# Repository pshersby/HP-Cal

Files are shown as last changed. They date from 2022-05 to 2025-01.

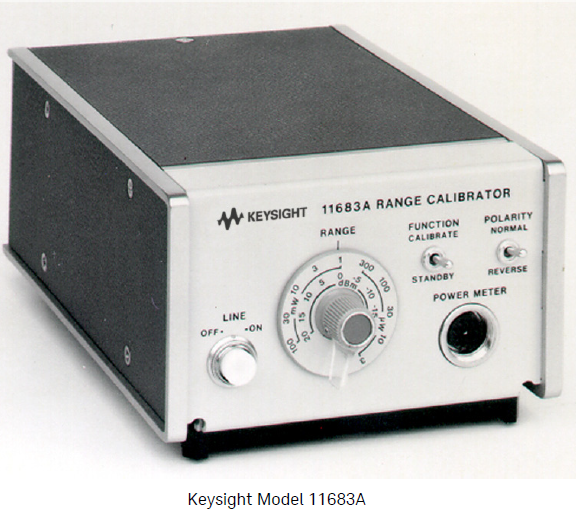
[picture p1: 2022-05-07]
Art/original.PNG

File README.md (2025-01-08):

# HP-Cal
 HP RF Meter Calibration

Version 1.1.1 8th Jan 2025
A3A1R1 previously labelled as both 196 and 464K in BOM corrected to 464k
Missing track from C11 put back in to join C11 to regulator
Missing track to base of Q11 replaced

Version 1.1. 
Contains th emodifications and fixes descbibed in my toutube videos.  Note that currently at rel 1.1 the artwork for the front panel and the 3d brackets have not been updated for the modified PCB layout which includes wider switch spacing etc. 

These Are Altium CircuitStudio schematics and PCB, they might load in Altium maker.

DefaultConfiguration/outputs contains the gerber and drill files, and a JLCPCB file with all the files needed for JLCPCB to make the pcb
The BOM is also in the above folder

A PDF with schematics, assembly locations etc is also available in that folder

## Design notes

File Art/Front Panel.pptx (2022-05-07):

## Front Panel

10-way 10mm
Sw 6.1mm
BNC 13mm
Out 18mm
Power 19mm

PKS 11683A
Range Calibrator

Calibrate

Standby

Int Ref

External

Positive

Reverse

Ref Out

Ref In

## Front Panel

10-way 10mm
Sw 6.1mm
BNC 13mm
Out 18mm
Power 19mm

PKS 11683A
Range Calibrator

Zero/
Standby

Calibrate

Int Ref

External

Positive

Reverse

Power

Ref Out

Ref In

Output

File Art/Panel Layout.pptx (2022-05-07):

## Panel Layout

60

30

30

30

PKS 11683A
Range Calibrator

Function
Calibrate

Standby

Reference
Internal

External

Output
Normal

Reverse

Ref Out

Ext Ref In

Power Meter

47

35

26

23

30

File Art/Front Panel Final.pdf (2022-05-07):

# Front Panel

10-way 10mm
Sw 6.1mm
BNC 13mm
Out 18mm
Power 19mm

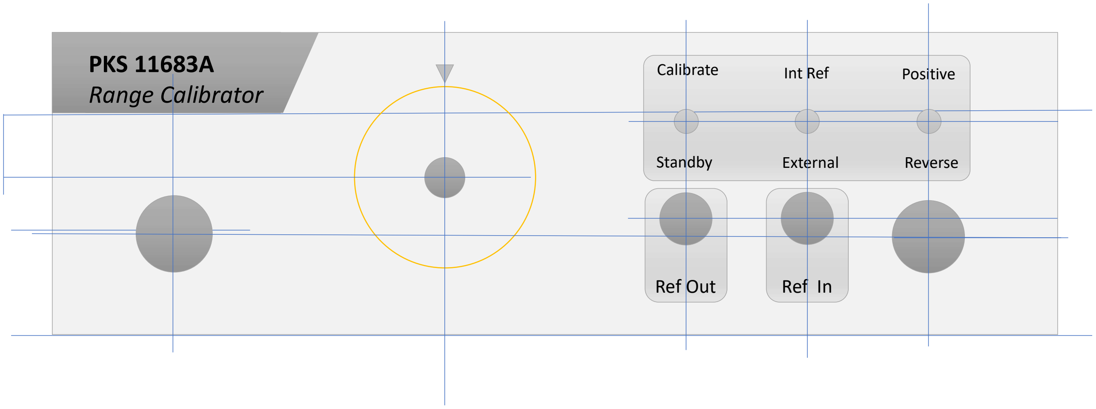
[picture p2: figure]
Ref Out; Ref; Calibrate; Standby; Int Ref; Positive; External; Reverse; PKS 11683A Range Calibrator

# Front Panel

10-way 10mm
Sw 6.1mm
BNC 13mm
Out 18mm
Power 19mm

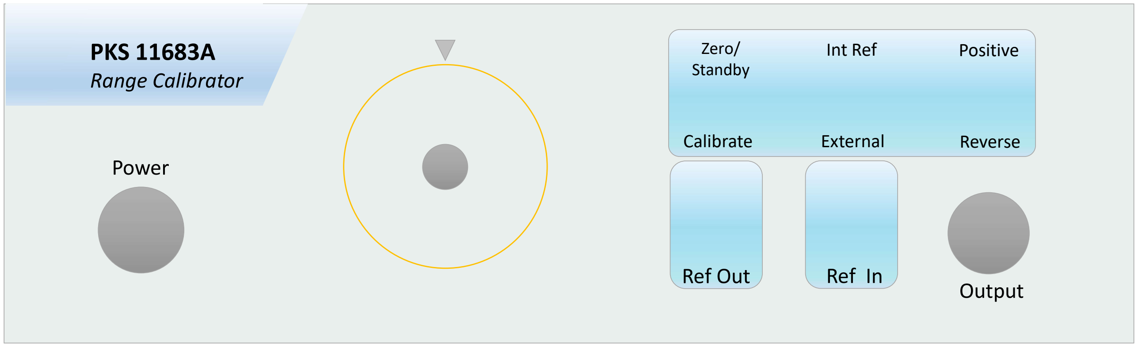
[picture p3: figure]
Ref Out; Ref In; Zero/ Standby; Calibrate; Int Ref; Positive; External; Reverse; PKS 11683A Range Calibrator; Power; Output

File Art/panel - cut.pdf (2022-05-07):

# Front Panel

10-way 10mm
Sw 6.1mm
BNC 13mm
Out 18mm
Power 19mm

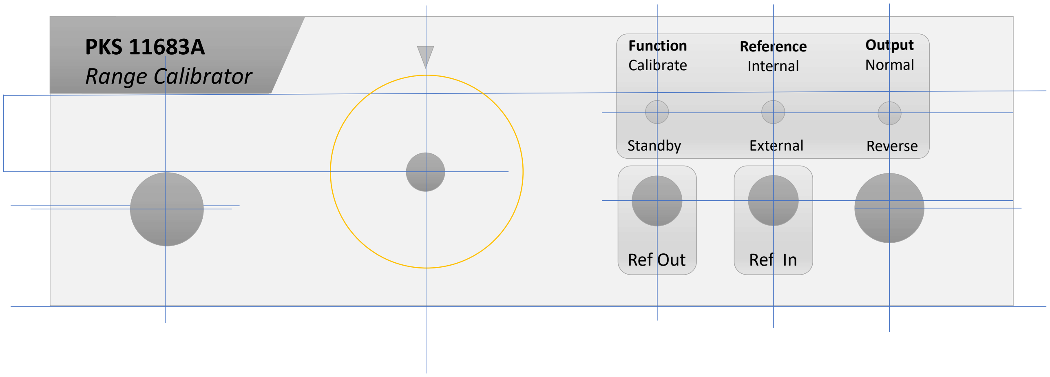
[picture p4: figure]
Ref Out; Ref; Function Calibrate; Standby; Reference Internal; Output Normal; External; Reverse; PKS 11683A Range Calibrator

# Front Panel

10-way 10mm
Sw 6.1mm
BNC 13mm
Out 18mm
Power 19mm

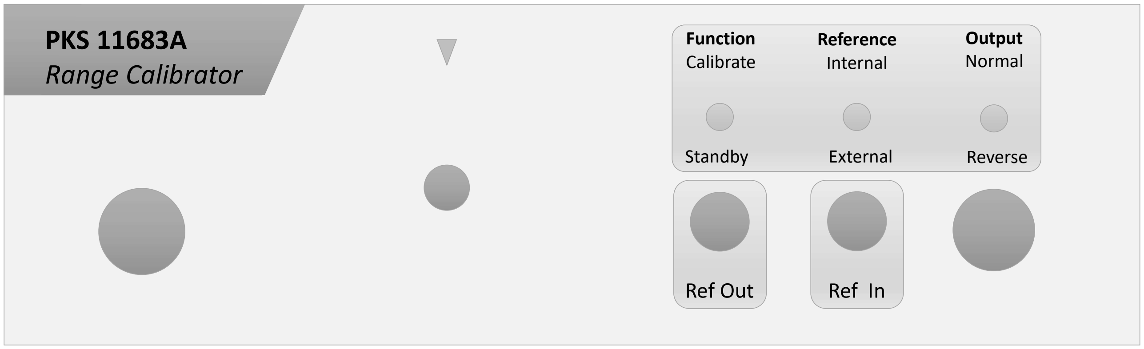
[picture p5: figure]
Ref Out; Ref In; Function Calibrate; Standby; Reference Internal; Output Normal; External; Reverse; PKS 11683A Range Calibrator

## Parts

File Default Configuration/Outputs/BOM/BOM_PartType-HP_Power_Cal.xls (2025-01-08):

Item # | Quantity | Designator | Description | Footprint | Comment | LibRef
1 | 1 | A1R3 | Resistor 196K 1% 0805 1/8W 10ppm/C | RESC2013X70X40LL20T20 | RES 196K 1% 0805 | CMP-2001-00110-5
2 | 1 | A3A1R1 | Resistor 464K 1% 0805 0.2W 10ppm/C | RESC2013X70X40LL20T20 | 464K 1% 0805 | CMP-2001-00110-5
3 | 1 | A3R2 | Resistor 3K!6 1% 0805 1/8W 10ppm/C | RESC2013X70X40LL20T20 | RES 3K16 1% 0805 | CMP-2001-00110-5
4 | 1 | A3R3 | Resistor 316 1% 0805 1/8W 10ppm/C | RESC2013X70X40LL20T20 | RES 316 1% 0805 | CMP-2001-00110-5
5 | 1 | BNC1 | BNC PCB Mount | BNC PCB Plastic | Ref Out | BNC PCB
6 | 1 | BNC2 | BNC Ref Out | BNC PCB Plastic | Ref In | BNC PCB
7 | 2 | C1, C9 | 47uF Tant 4V 1411 | FP-TAJB-MFG | 47uF TA | CMP-04424-000035-1
8 | 4 | C2, C3, C7, C8 | 100pF 0805 | CAPC2113X88X50NL30T25 | 100pF 0805 | CMP-2007-00001-1
9 | 3 | C4, C12, C14 | 1206 (3216 Metric) Chip Capacitor | CAPC1206(3216)150_L | 3.3UF | CMP-1590-00001-1
10 | 1 | C5 | 0.1uF 0805 | CAPC2113X88X50NL30T25 | 0.1uF 0805 | CMP-2007-00001-1
11 | 1 | C6 | 0.01uF 0805 | CAPC2113X88X50NL30T25 | 0.01uF 0805 | CMP-2007-00001-1
12 | 1 | C10 | CAP TANT 100u 10V | FP-TPE-D4-MFG | 100u 10V TA | CMP-05428-000010-1
13 | 1 | C11 | CAP TANT 10u 25V | FP-TPE-D4-MFG | 10u 25V TA | CMP-05428-000010-1
14 | 1 | C13 | 1uF 0805 | CAPC2113X88X50NL30T25 | 1uF 0805 | CMP-2007-00001-1
15 | 1 | CHS-GND | Socket | PIN1 | T0 Chassis Gnd | Socket
16 | 1 | Fuse | Fuse | Fuse Holder 20mm PCB with Cover | Fuse 50mA T | Fuse
17 | 2 | IBC1, IBC2 | Header, 4-Pin | HDR1X4 | Header 4 | Header 4
18 | 1 | L1 | Inductor 6.8uH | 2.5x2 Inductor | 6.8uH | Inductor
19 | 4 | L, N, SW-1, SW-2 | Socket | PIN1 | Socket | Socket
20 | 1 | P6 | Header, 2-Pin | HDR1X2 | Power In | Header 2
21 | 1 | P7 | Header, 2-Pin | HDR1X2 | Power Ref | Header 2
22 | 1 | P8 | Header, 2-Pin | HDR1X2 | Power LED | Header 2
23 | 1 | P9 | Header, 8-Pin | HDR1X8 | Header 8 | Header 8
24 | 1 | P10 | Header, 2-Pin | HDR1X2 | Ext 18-24V | Header 2
25 | 2 | Q1, Q2 | JFET - VHF / UJFET Chopper | ONSC-SOT-23-3-318-08_V | MMBFJ111 | CMP-1062-00038-1
26 | 1 | Q3 | 2SC3837K | SC-59 | 2SC3837K | NPN
27 | 1 | R1 | Resistor 31.6 0.1% 0805 0.2W 10ppm/C | RESC2013X70X40LL20T20 | RES 31.6 0.1% 0805 | CMP-2001-00110-5
28 | 1 | R2 | Resistor 0.02 1% 0805 0.5W 50ppm/C | RESC2013X70X40LL20T20 | RES 0.02 1% 0805 | CMP-2001-00110-5
29 | 1 | R3 | Resistor 68.1 0.1% 0805 0.2W 10ppm/C | RESC2013X70X40LL20T20 | RES 68.1 0.1% 0805 | CMP-2001-00110-5
30 | 1 | R4 | Resistor 0.27 1% 0805 0.2W 10ppm/C | RESC2013X70X40LL20T20 | RES 0.27 1% 0805 | CMP-2001-00110-5
31 | 2 | R5, R5a | Resistor 432 0.1% 0805 0.2W 10ppm/C | RESC2013X70X40LL20T20 | RES 432 0.1% 0805 | CMP-2001-00110-5
32 | 1 | R6 | Resistor 0.39 1% 0805 0.2W 10ppm/C | RESC2013X70X40LL20T20 | RES 0.39 1% 0805 | CMP-2001-00110-5
33 | 1 | R7 | Resistor 22.6 0.1% 0805 0.2W 10ppm/C | RESC2013X70X40LL20T20 | RES 22.6 0.1% 0805 | CMP-2001-00110-5
34 | 1 | R8 | Resistor 665 0.1% 0805 0.2W 10ppm/C | RESC2013X70X40LL20T20 | RES 665 0.1% 0805 | CMP-2001-00110-5
35 | 1 | R9 | Resistor 2K2 0.5% 0805 0.2W 10ppm/C | RESC2013X70X40LL20T20 | RES 2K2 0.5% 0805 | CMP-2001-00110-5
36 | 1 | R10 | Resistor 7.32 0.1% 0805 0.2W 10ppm/C | RESC2013X70X40LL20T20 | RES 7.32 0.1% 0805 | CMP-2001-00110-5
37 | 1 | R11 | Resistor 7.15K 0.1% 0805 0.2W 10ppm/C | RESC2013X70X40LL20T20 | RES 7.15K 0.1% 0805 | CMP-2001-00110-5
38 | 1 | R12 | Resistor 59 0.1% 0805 0.2W 10ppm/C | RESC2013X70X40LL20T20 | RES 59 0.1% 0805 | CMP-2001-00110-5
39 | 1 | R13 | Resistor 100 0.1% 0805 0.2W 10ppm/C | RESC2013X70X40LL20T20 | RES 100 0.1% 0805 | CMP-2001-00110-5
40 | 2 | R14, R14b | Resistor 53.6K 0.1% 0805 0.2W 10ppm/C | RESC2013X70X40LL20T20 | RES 53.6K 0.1% 0805 | CMP-2001-00110-5
41 | 2 | R15, R15a | Resistor 160 0.1% 0805 0.2W 10ppm/C | RESC2013X70X40LL20T20 | RES 160 0.1% 0805 | CMP-2001-00110-5
42 | 2 | R16, R16a | Resistor 274K 0.1% 0805 0.2W 10ppm/C | RESC2013X70X40LL20T20 | RES 274K 0.1% 0805 | CMP-2001-00110-5
43 | 1 | R17 | Resistor 2.8K 0.1% 0805 0.2W 10ppm/C | RESC2013X70X40LL20T20 | RES 2.8K 0.1% 0805 | CMP-2001-00110-5
44 | 1 | R18 | Resistor 536K 0.1% 0805 1/8W 10ppm/C | RESC2013X70X40LL20T20 | RES 536K 0.1% 0805 | CMP-2001-00110-5
45 | 2 | R19, R19a | Resistor 25K 0.1% 0805 0.1W 10ppm/C | RESC2013X70X40LL20T20 | RES 25K 0.1% 0805 | CMP-2001-00110-5
46 | 1 | R20 | Resistor 360K 0.1% 0805 1/8W 10ppm/C | RESC2013X70X40LL20T20 | RES 360K 0.1% 0805 | CMP-2001-00110-5
47 | 1 | R21 | Resistor 3K3 0.1% 0805 0.2W 10ppm/C | RESC2013X70X40LL20T20 | RES 3K3 0.1% 0805 | CMP-2001-00110-5
48 | 1 | R29 | Resistor 196 1% 0805 0.2W 10ppm/C | RESC2013X70X40LL20T20 | RE196 1% 0805 | CMP-2001-00110-5
49 | 2 | R31, R33 | Resistor 15 1% 0805 0.2W 10ppm/C | RESC2013X70X40LL20T20 | RES 15 1% 0805 | CMP-2001-00110-5
50 | 3 | R32, R34, R35 | Resistor 1K 1% 0805 0.2W 10ppm/C, Resistor 1K1% 0805 0.2W 10ppm/C, Resistor 1K1% 0805 0.2W 10ppm/C | RESC2013X70X40LL20T20 | RES 1K 1% 0805 | CMP-2001-00110-5
51 | 1 | R36 | Resistor 240 1% 0805 0.2W 10ppm/C | RESC2013X70X40LL20T20 | RES 240 1% 0805 | CMP-2001-00110-5
52 | 1 | R37 | Resistor 2k2 5% 0805 0.2W 10ppm/C | RESC2013X70X40LL20T20 | RES 2k2 5% 0805 | CMP-2001-00110-5
53 | 1 | R38 | Resistor 10K 5% 0805 0.2W 50ppm/C | RESC2013X70X40LL20T20 | RES 10K 5% 0805 | CMP-2001-00110-5
54 | 1 | RT1 | RES 31.6 250ppm 0805 | RESC2013X70X40LL20T20 | RES 31.6 250ppm 0805 | CMP-2001-00110-5
55 | 2 | SC1, SC2 |  | ScreenConnection | ScreenConnection | ScreenConnection
56 | 1 | SW1 | Rotary Switch 10way PCB CKN10954-ND | SW_ROT_4x12 | Rotary Switch 10way | Rotary_Switch_1x10
57 | 1 | SW2 | DPDT Switch | DPDT Toggle E switch | DPDT Switch POL | DPDT Switch
58 | 1 | SW3 | CAL/SDBY DPDT | DPDT Toggle E switch | CAL/SBY DPDT | DPDT Switch
59 | 1 | SW4 | DPDT Switch | DPDT Toggle E switch | INT/EXT DPDT | DPDT Switch
60 | 1 | T1 | AC-DC Regulated Module 24V | IRM-02 Moule SM | AC-DC Reg | AC-DC Reg Module
61 | 1 | Trm1 | Trimmer | 3214W Trimmer | Trm 1k | Trimmer
62 | 1 | U1 | 500mA, Medium Current 1.2 to 37 V Adjustable Voltage Regulator, 3-Pin DPAK, Tape and Reel | TO-252_L | LM317MDT-TR | CMP-0244-00074-1

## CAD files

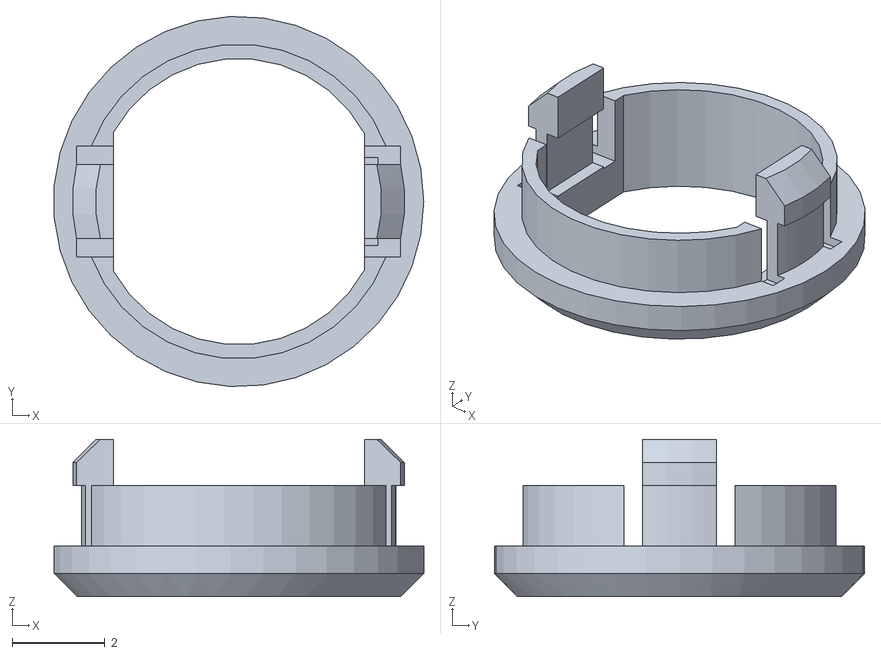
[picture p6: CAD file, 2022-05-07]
3d/bezel.stl
7.98 x 7.99 x 3.40

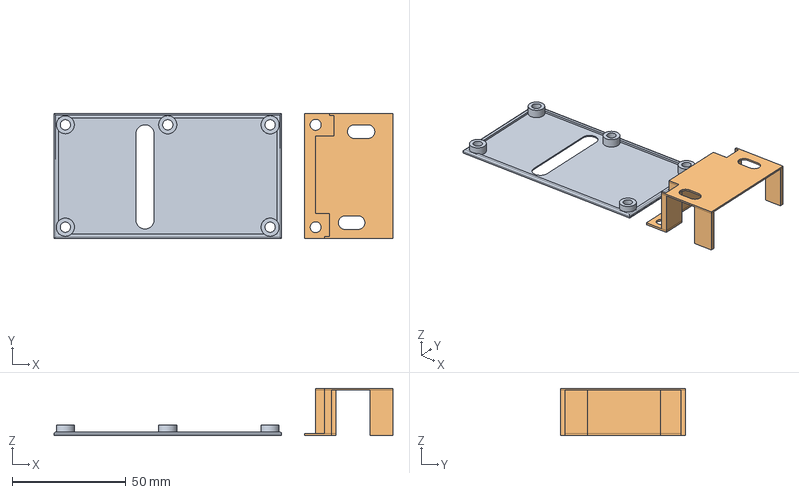
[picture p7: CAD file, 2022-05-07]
3d/HV Insulation.FCStd
149.0 x 55.0 x 20.8 mm
Insulator

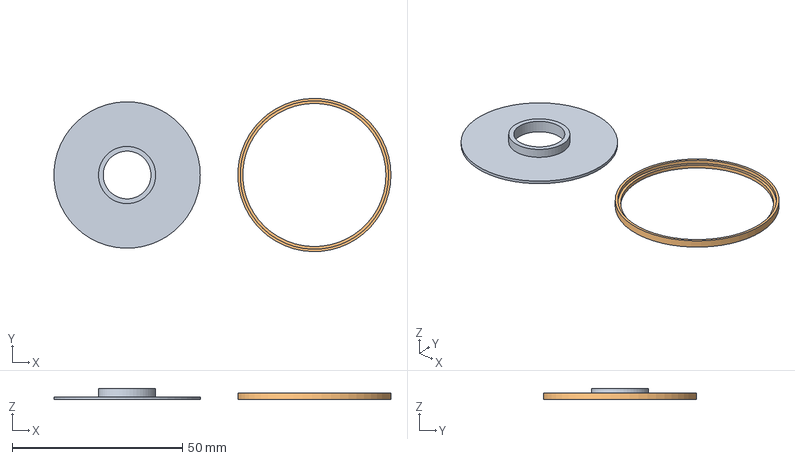
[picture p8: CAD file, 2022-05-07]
3d/knob scale ver 2 pt 1.FCStd
99.0 x 45.0 x 3.30 mm

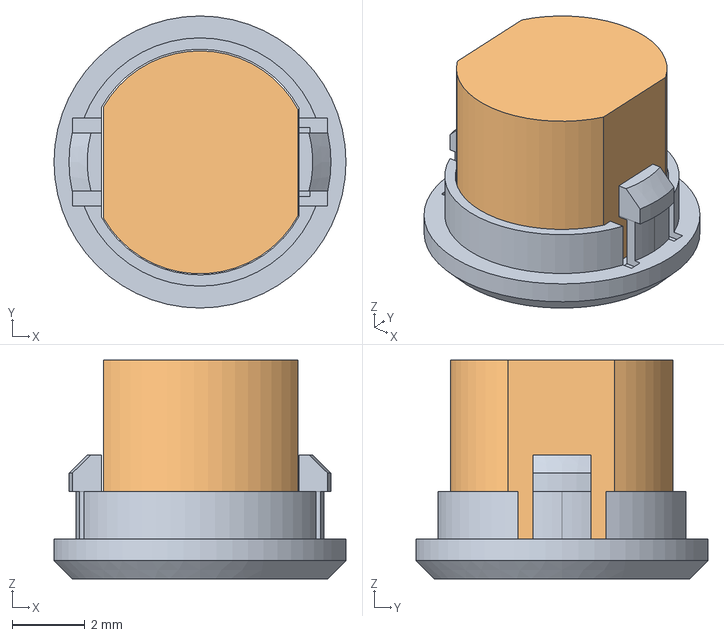
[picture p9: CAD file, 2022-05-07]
3d/switch bezel.FCStd
8.00 x 8.00 x 6.00 mm

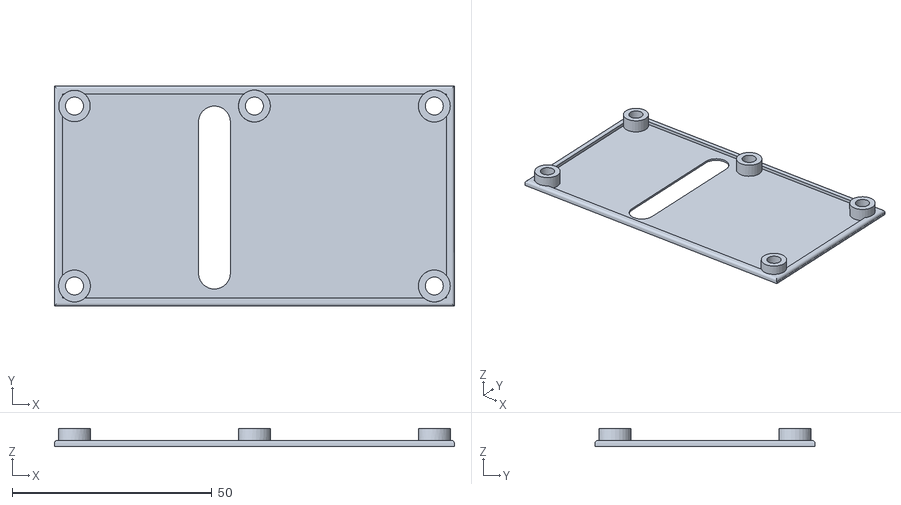
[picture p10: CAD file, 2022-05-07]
3d/Insulating Base.stl
100.0 x 55.0 x 4.60

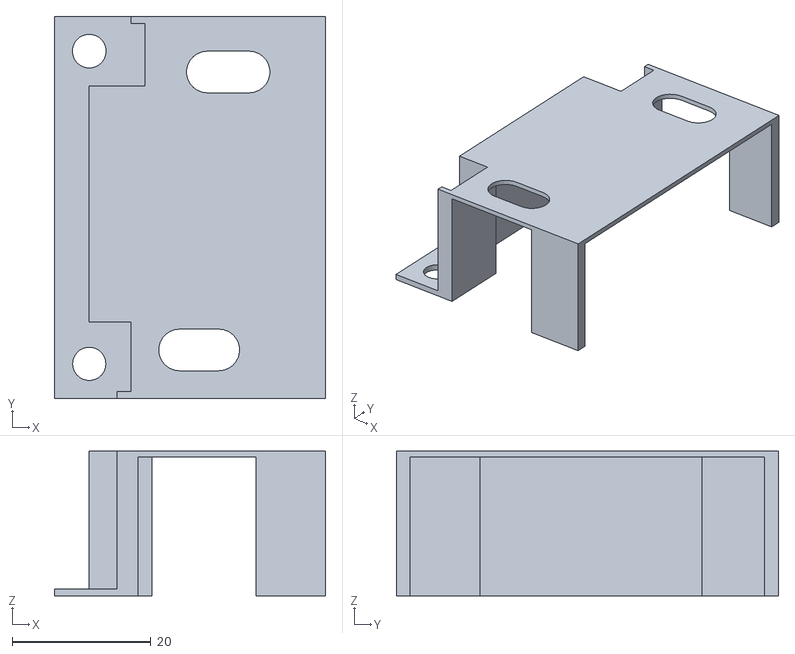
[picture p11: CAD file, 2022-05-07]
3d/Insulting Cap.stl
39.0 x 55.0 x 20.8

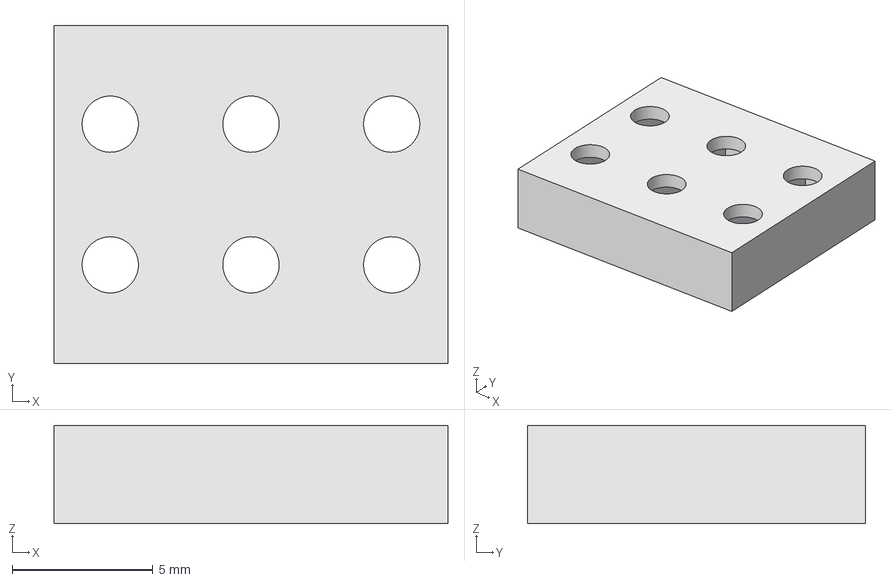
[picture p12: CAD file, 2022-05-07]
3d/switch spacer.FCStd
14.0 x 12.0 x 3.50 mm

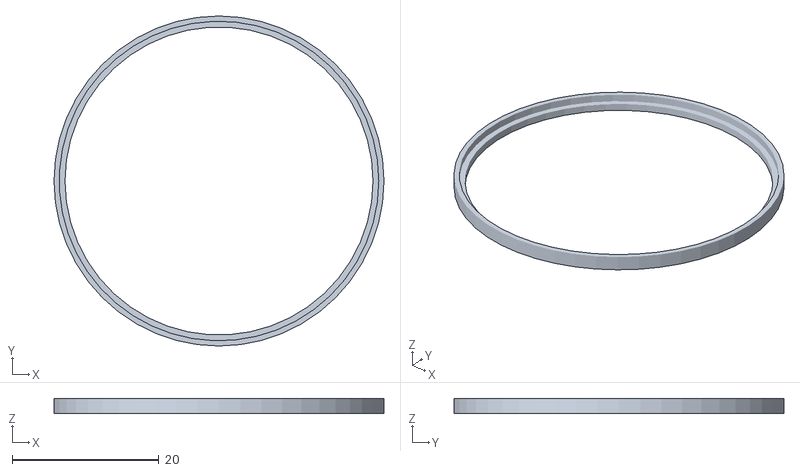
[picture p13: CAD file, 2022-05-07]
3d/knob scale ver 2 pt2.stl
45.0 x 45.0 x 2.00

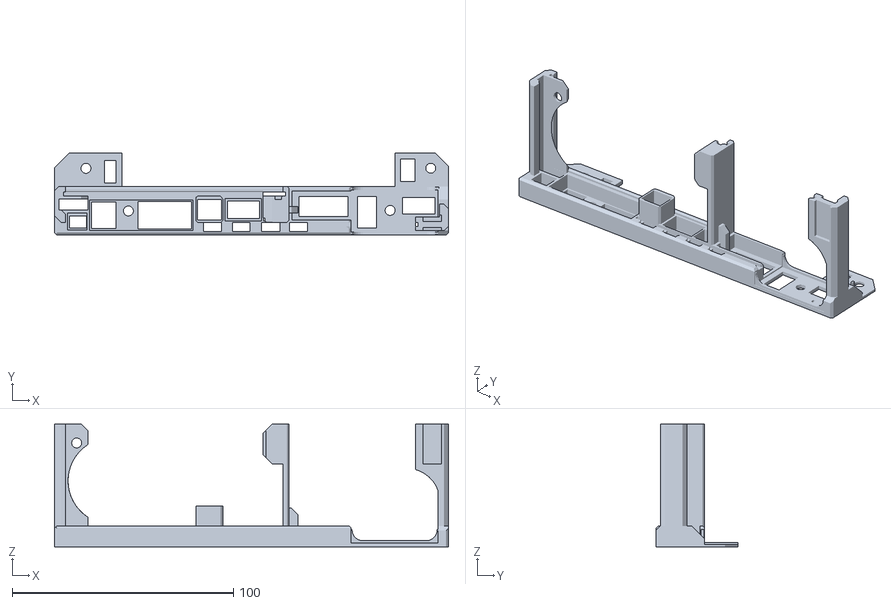
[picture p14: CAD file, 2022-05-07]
3d/pcb support frame.stl
178.1 x 37.0 x 55.5

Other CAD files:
3d/knob scale ver 2 pt1.stl
3d/switch spacer.stl

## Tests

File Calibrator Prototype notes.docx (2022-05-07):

Calibrator Prototype notes for production

1. Select a nice, available box
2. Rearrange board so that
  a. Bigger gap between switches and BNC - Done
  b. BNC are lower - Done
  c. Depth offset BNC vs switch is better – perhaps BNC on back board, switch on front? – used spacer for moment
3. Can we solder the 12-way onto a board and have it behind main panel on a set-back? Yes but prevents switching spike tuning
4. PCB mount IEC socket with built-in fuse on power board – and PCB mains switch?
5. Change power button and use separate LED to improve isolation gap
6. Mark polarities on all boards (DONE)
7. V Cut or route boards

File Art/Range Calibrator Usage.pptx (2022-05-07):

## Range Calibrator Usage

POWER METER
UNDER REPAIR

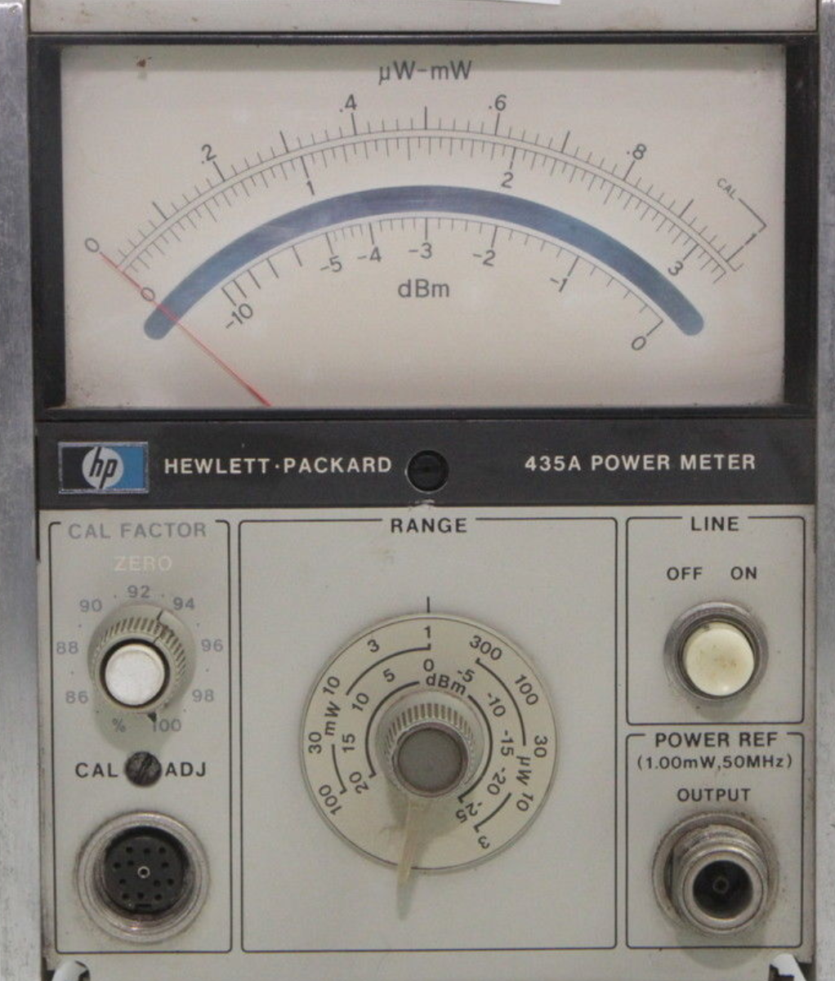
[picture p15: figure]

VOLT METER

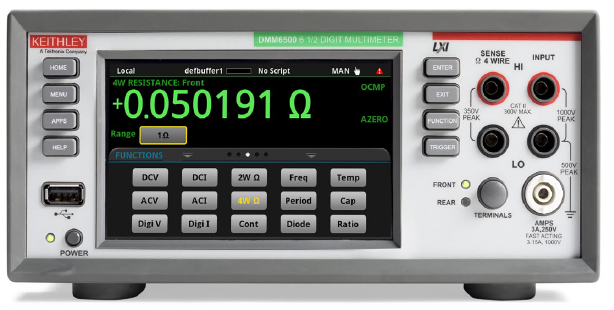
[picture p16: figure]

CALIBRATOR

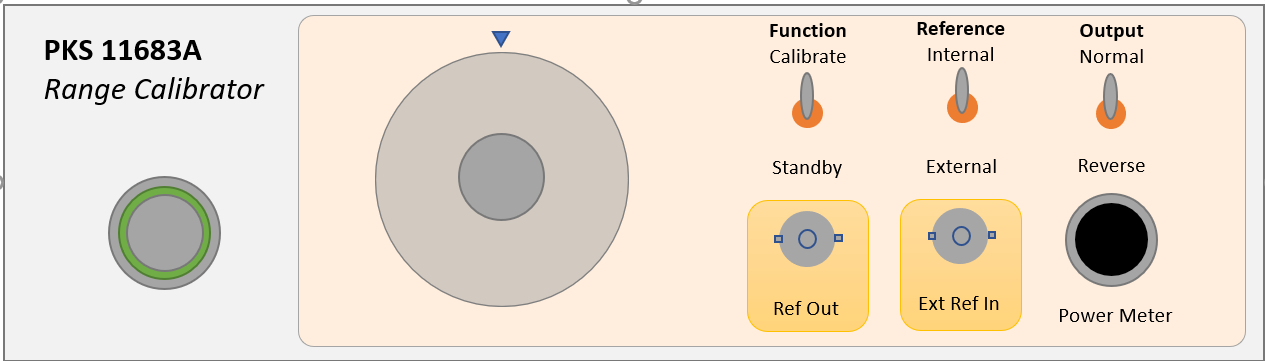
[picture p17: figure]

Rear panel
recorder output

## Voltage Divider method

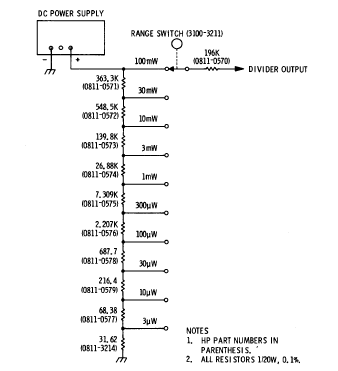
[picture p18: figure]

12.8V

Spare Sensor

Amp

Detector
Thermocouple / Diode

Disconnect
Detector

Chopper

## Block Diagram

Amphenol
T 3638 000

Zero

Line
Supply

Int/Ext
Ref

Polarity
Switch

Power 12.8V

Divider

Chopper
2x FET

Amp
1 NPN

Out

Feedback

Ext
Ref

Chop

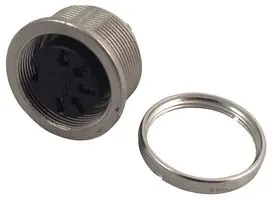
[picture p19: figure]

## Box and layout - draft

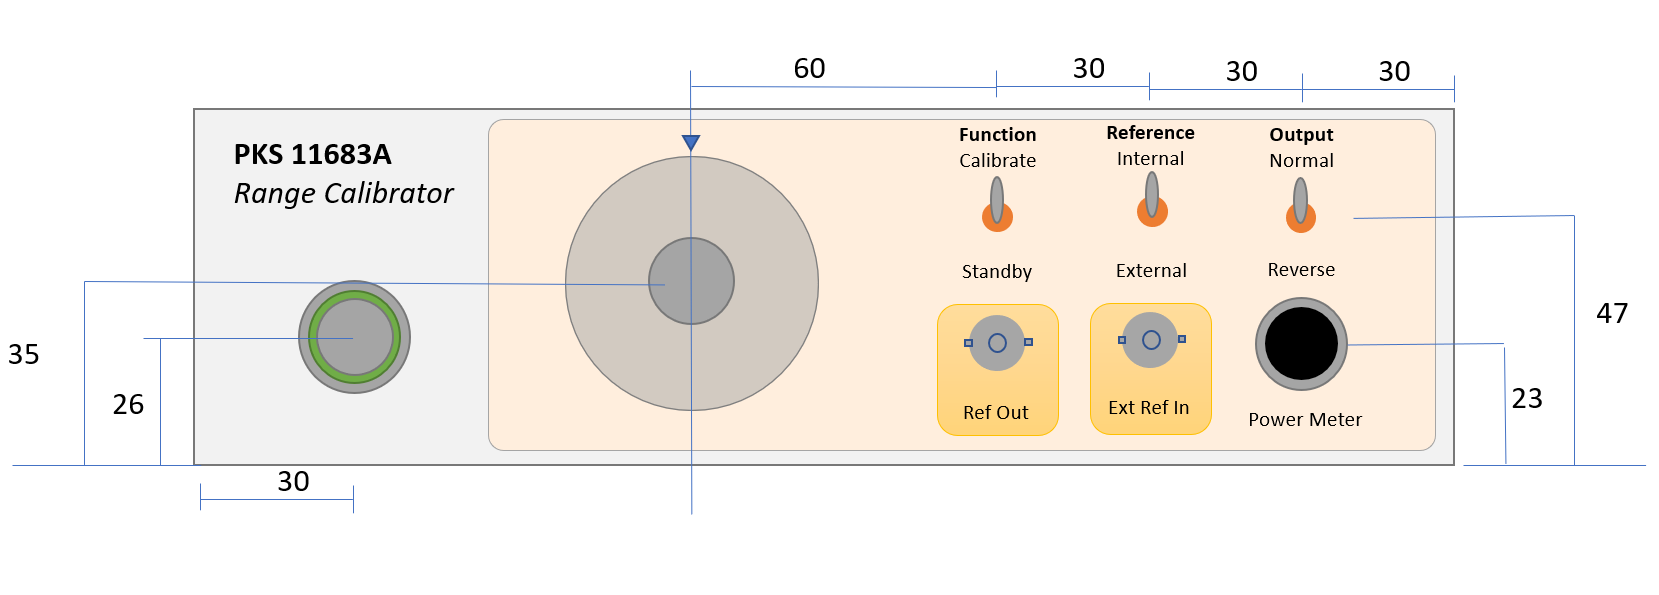
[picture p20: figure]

PSU

Height 76mm
Width 250mm
Depth (front to back) 165mm
Int Depth 150mm
Support plate 10mm from base

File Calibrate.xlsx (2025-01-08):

 |  | MEASURED VOLTAGE | ACTUAL RATIO | MIN Ratio | Target Ratio | MAX Ratio | Ideal Volts (H01 supplement) | -0.20% | +0.2%
100mW |  | 15.8 | 1 | 1 | 1 | 1 | 15.8 | 15.7684 | 15.8316
30mW |  | 4.708 | 3.355989805 | 3.3457 | 3.35305 | 3.3604 | 4.7121 | 4.7026758 | 4.7215242
10mW |  | 1.463 | 10.79972659 | 10.768 | 10.7915 | 10.815 | 1.4641 | 1.4611718 | 1.4670282
3mW |  | 0.458135 | 34.48765102 | 34.394 | 34.4695 | 34.545
1mW |  | 0.144923 | 109.0234124 | 108.76 | 108.995 | 109.23 | 0.145 | 0.14471 | 0.14529
300uW |  | 0.04584 | 344.6771379 | 343.95 | 344.7 | 345.45 | 0.045837 | 0.045745326 | 0.045928674
100uW |  | 0.014494 | 1090.106251 | 1087.92978 | 1090.11 | 1092.29022 | 0.014494 | 0.014465012 | 0.014522988
30uW |  | 0.004583 | 3447.523456 | 3440.62496 | 3447.52 | 3454.41504 | 0.0045832 | 0.0045740336 | 0.0045923664
10uW |  | 0.00145 | 10896.55172 | 10874.8068 | 10896.6 | 10918.3932 | 0.0014501 | 0.0014471998 | 0.0014530002
3uW |  | 0.0004587 | 34445.17114 | 34376.3096 | 34445.2 | 34514.0904 | 0.00045869 | 0.00045777262 | 0.00045960738
 |  |  | Green if in range | Note these ratios have are roughly 0.2% tolerance
 | Ideal Range Volts from the H01 ?Supplement all +-0.2%
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

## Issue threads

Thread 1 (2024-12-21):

Error in JLCPCB gerbers?

mankangustafsson, 2024-12-21:
I'm currently building this and after tweaking resistor values I'm close to the values in the tables in the service manual.
So next item was to connect a power meter. First it did not recognize that the calibrator was connected.
But after connecting J, K and M pin to the F pin in the output connector, the meter (HP437B) now says "Please zero".

However zeroing fails. While measuring components and checking my solder joints, I found that C5, C6 and C7 is not connected to the base of Q3.
The fix is to solder a wire from the C5 via to C8. Let me know if my finding and fix are correct.
However zeroing still fails.

I'll resume the fault hunting in about a week but meanwhile I'm happy to get any hints on how to continue.

mankangustafsson, 2025-01-02:
I also found that I had mounted 196Ohm for A3A1R1 as the BOM says but the schema says 464kOhm. After I fixed that my HP437B intermittently succeeds to zero. Maybe its an issue with the power meter itself. My HP438A seems to zero fine or maybe it does not report zero failures visually.

pshersby, 2025-01-08:
I had to use a wire in my build but I thought I had released the pcb fix onto Github. -  I will have to check.  Perhaps I forgot to regnerate the gerbers after updating. Be careful tweeking the resistors then measuring the voltages as shown in the HP manual - the problem is that they used a multimeter with 1M input impedence to create their table, whereas almost all current meters are 10M and that is essentially placed in parallel with the resistor chosen by the switch and as you go through the range it does make a significant difference to the output voltage.  You can use a modern meter if you put 1111111 ohms across the voltage input or do a lot of calculations to work out the right voltages for a 10M meter.  I built a board for someone using 0.1% resistors and then spent forever checking resistor values before I realised the problem was the specific HP meter that they specify.  I will try and fix any problems you find with the BOM.  It may sound obvious but make sure you switch the calibrator to the "zero position" when you zero it!

pshersby, 2025-01-08:
Just checked it out to take a look.  I had fixed the fault that I found on mine, but int he process two others seemed to have appeared - the one you mentioned on Q3 and oddly it looks like C11 positive side is not connected to the regulator either.  Not at all sure how that happened!  Anyway all updated now.

pshersby, 2025-01-08:
All updated as described

mankangustafsson, 2025-01-08:
Thanks for the confirmation about Q3. The wire in the video was the Q2 base, right?
I'll patch my board for the C11, I do not think it will make much difference but it feels good to make it as it was intended to.

Regarding the voltage and resistance measurements I have realized that the HP documentation is contradictory together with what you are saying,  or at least confusing me.

HP11638A manual says:
Describing the connectors
`6 D.C. REFERENCE OUTPUT connector. DC reference voltage output from RANGE Switch. Load resistance must be ≥ 100 MΩ for proper operation of the 11683A.`

Range Switch Performance test says
`2 Set the digital voltmeter controls so measurements of up to +20 Vdc may be made. All measurements are to be 5-digit resolution.`

This I interpret as disabling auto ranging on the DMM for measuring the 15.8V input, then measure the other values:
From the 3455A manual
```
0.1 through 10V range > 100GOhm
100V and 1000V range 10 MOhm +-0.1% (with auto-cal off)
```
Here we have the contradiction between 10 MOhm and 100MOhm.

I have measured with my Agilent 34401 which on manual range (100V) which has:
```
0.1 V, 1 V, 10 V ranges Selectable 10 MΩ or >10 GΩ
100 V, 1000 V ranges 10 MΩ ±1%
```
From this I do not see how the voltage measurements are done with 1MOhm input impedance.

What is the proper way to verify the voltages?
I think tweaking the 15.8 input voltage with auto range, then measure the rest with 10 GΩ. Do you agree?

Also, the manual must be wrong about the resistance measurements, the line switch must be off as well. There are other errors in the manual as well.

Best regards
Marcus

pshersby, 2025-01-09:
I remember having major problems with that bit (and clearly with my memory).  I've dug out the old simulator and spreadsheet I used to finally figure it out and sort out my dodgy recollection.

The problem was that the meter specified is >100M input impedence for all but the 100mW range setting (15.8V approx), but in a later supplement the meter specified 10M (and so I set mine to 10M)  this meant it read voltages up to the 3mW range in spec but above that they went out of spec until I got to the 100mW which is connected directly to the ultra low impedence power reference.   The answer is you use the best you have for the 100mW range (which is directly connected to teh output of the regulator so meter impedence is less of an issue) and then try to use 100M or above  for everything else which is going to be below 10V although the meter impedence matters less when you go below the 1mW range.

In terms of calibration it is the ratio of the resistors that is critical not the actual voltage steps which is why the manual specifies permitted 0.2% ratio ranges but the HP 11683A H01 manual just gives a list of voltages instead of ratios all the way through the range - handy!    I have added my manuals to the data folder.

Since your power meter references everything to the 1mW range this is your baseline.   Correct calibration is done as follows - the reference voltage is set to roughly 15.8V.  Then set it in the calibrate position and pick the 1mW range and connect the volt meter to the output of the divider (Ref out socket);  adjust power supply to get a reading of as close to 145mV as you can.  Then measure and write down the voltage output for each range with the highest impedence meter you can find.  To get the list of ratios just divide the voltage you noted by the voltage you measured on the  100mW position so for example on the 1mW range you might have 0.144923V/15.8V = 109.023412 which is in the specified range 108.76 to 109.23

I have added a spreadsheet to the root directory called calibrate.xls in it you can just type in the voltages you find and it will calcuate the ratios - it also has the list of voltages from the H01 suplement with +-0.2% ready calculated  The figures already populated are the ones I took from a simulation uising a 100M impedence load for the meter.

pshersby, 2025-01-09:
I also added a simulation of the divider.  My simulations are in Micro-cap version 12 which is available free.  After loading the simulation just start the Transient analysis from the menu, accept the parameters it offers then towards the bottom click on the "Simulation.cir" tab to hide the graph that just appeared.  The Output voltage is shown measureed across the 100Meg resistor that models the meter., grab the horizontal link and move it to simulate different switch positions.  The output will update in real time.

mankangustafsson, 2025-01-09:
Thanks for the proposed adjustment and measurement schema and the updated manuals. At the moment I have a multiple values out of spec but just a few that are way off  (>0.5%). I think I will remove my resistor tweaks and restore the original values and measure again.

I'll also see if I can get the simulation going.

mankangustafsson, 2025-01-09:
Success :-)

I restored to the original resistor values and now all voltages are in range and all resistances except the 3uW one, it reads 31.80 Ohms, limit is 31.72Ohms. I'll let that one slide. ;-)

Also, I had no issues getting the simulation going.

And by the way, I think some of my problems with zeroing the meter could be due a bad probe cable. Also the the HP437B I have is in an unknown state. Now I'm going the performance test my HP438A

Closed 2025-01-08.

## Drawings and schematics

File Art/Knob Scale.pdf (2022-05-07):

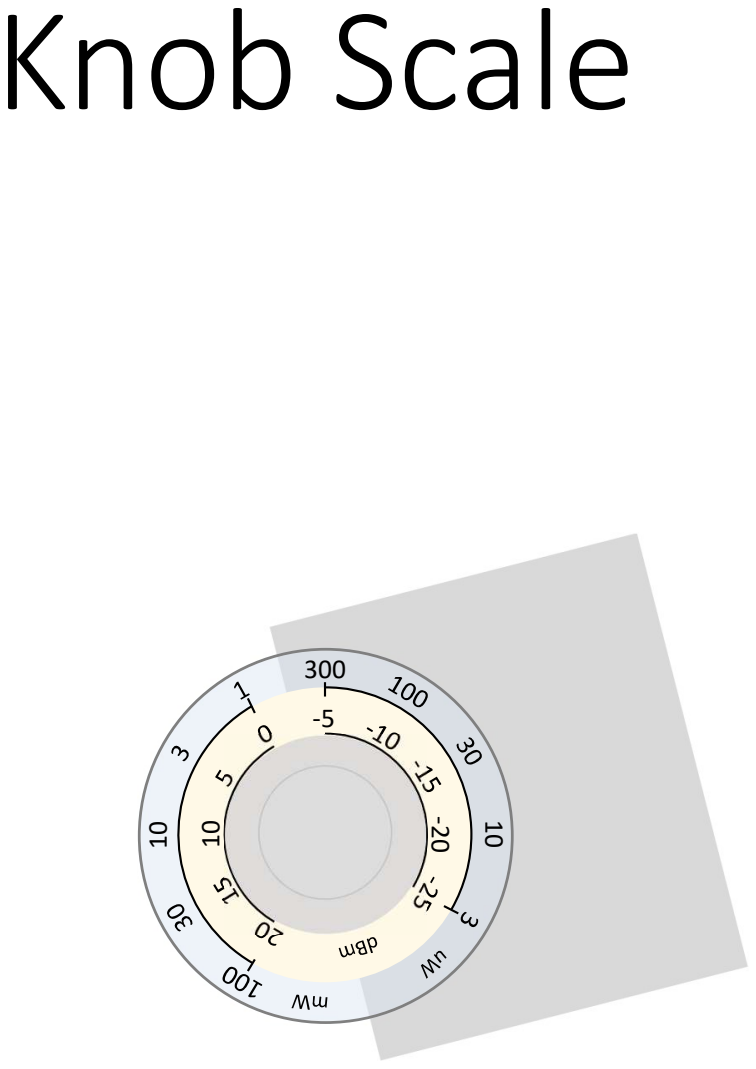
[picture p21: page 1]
Knob Scale 10

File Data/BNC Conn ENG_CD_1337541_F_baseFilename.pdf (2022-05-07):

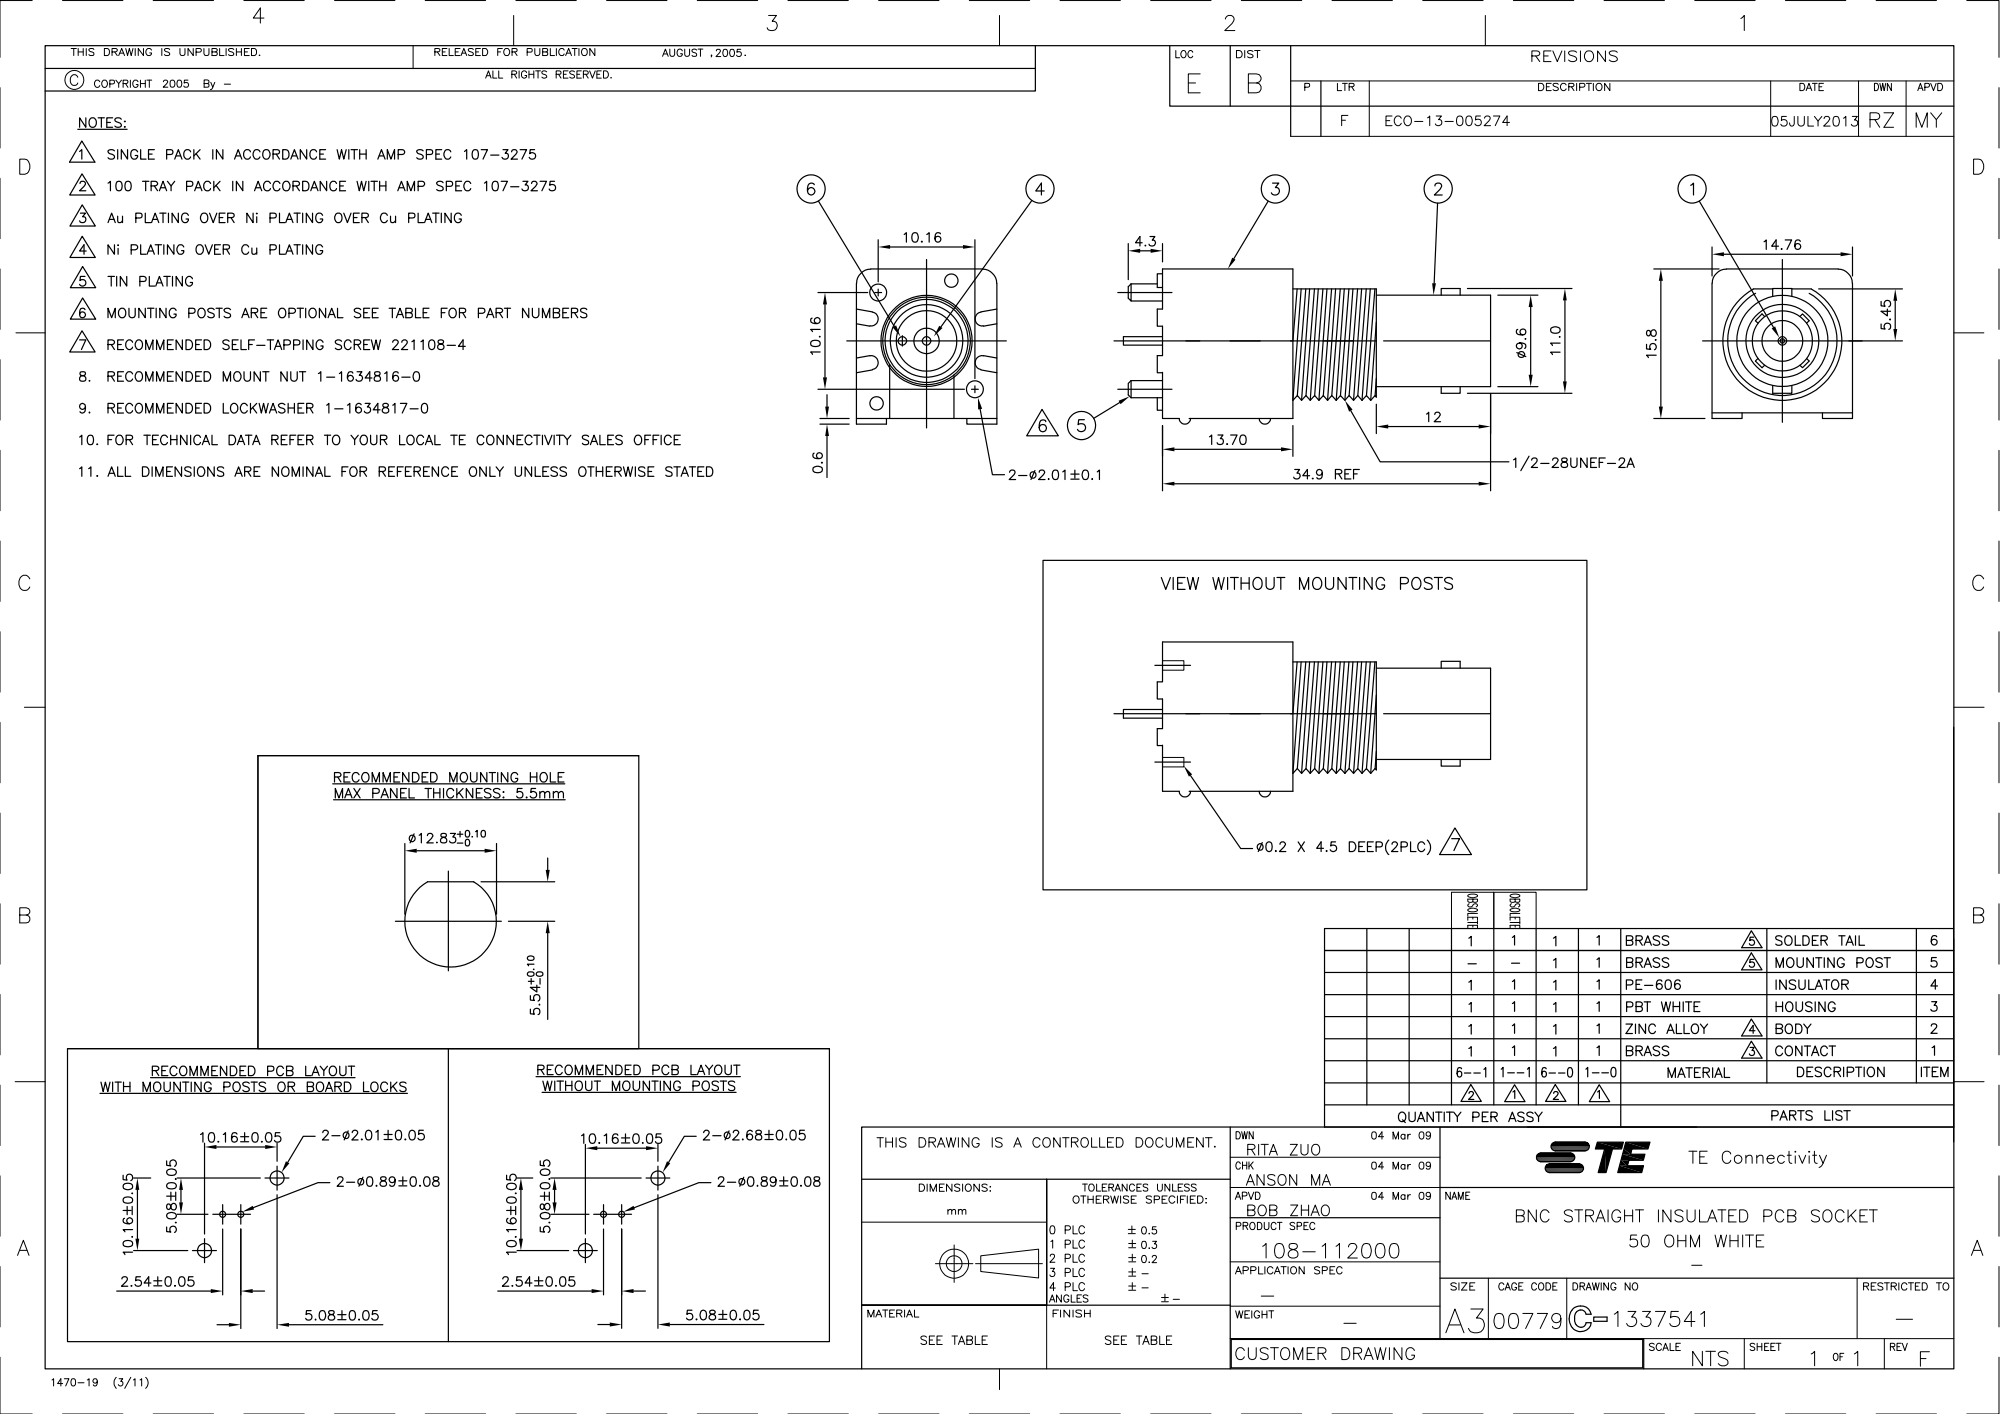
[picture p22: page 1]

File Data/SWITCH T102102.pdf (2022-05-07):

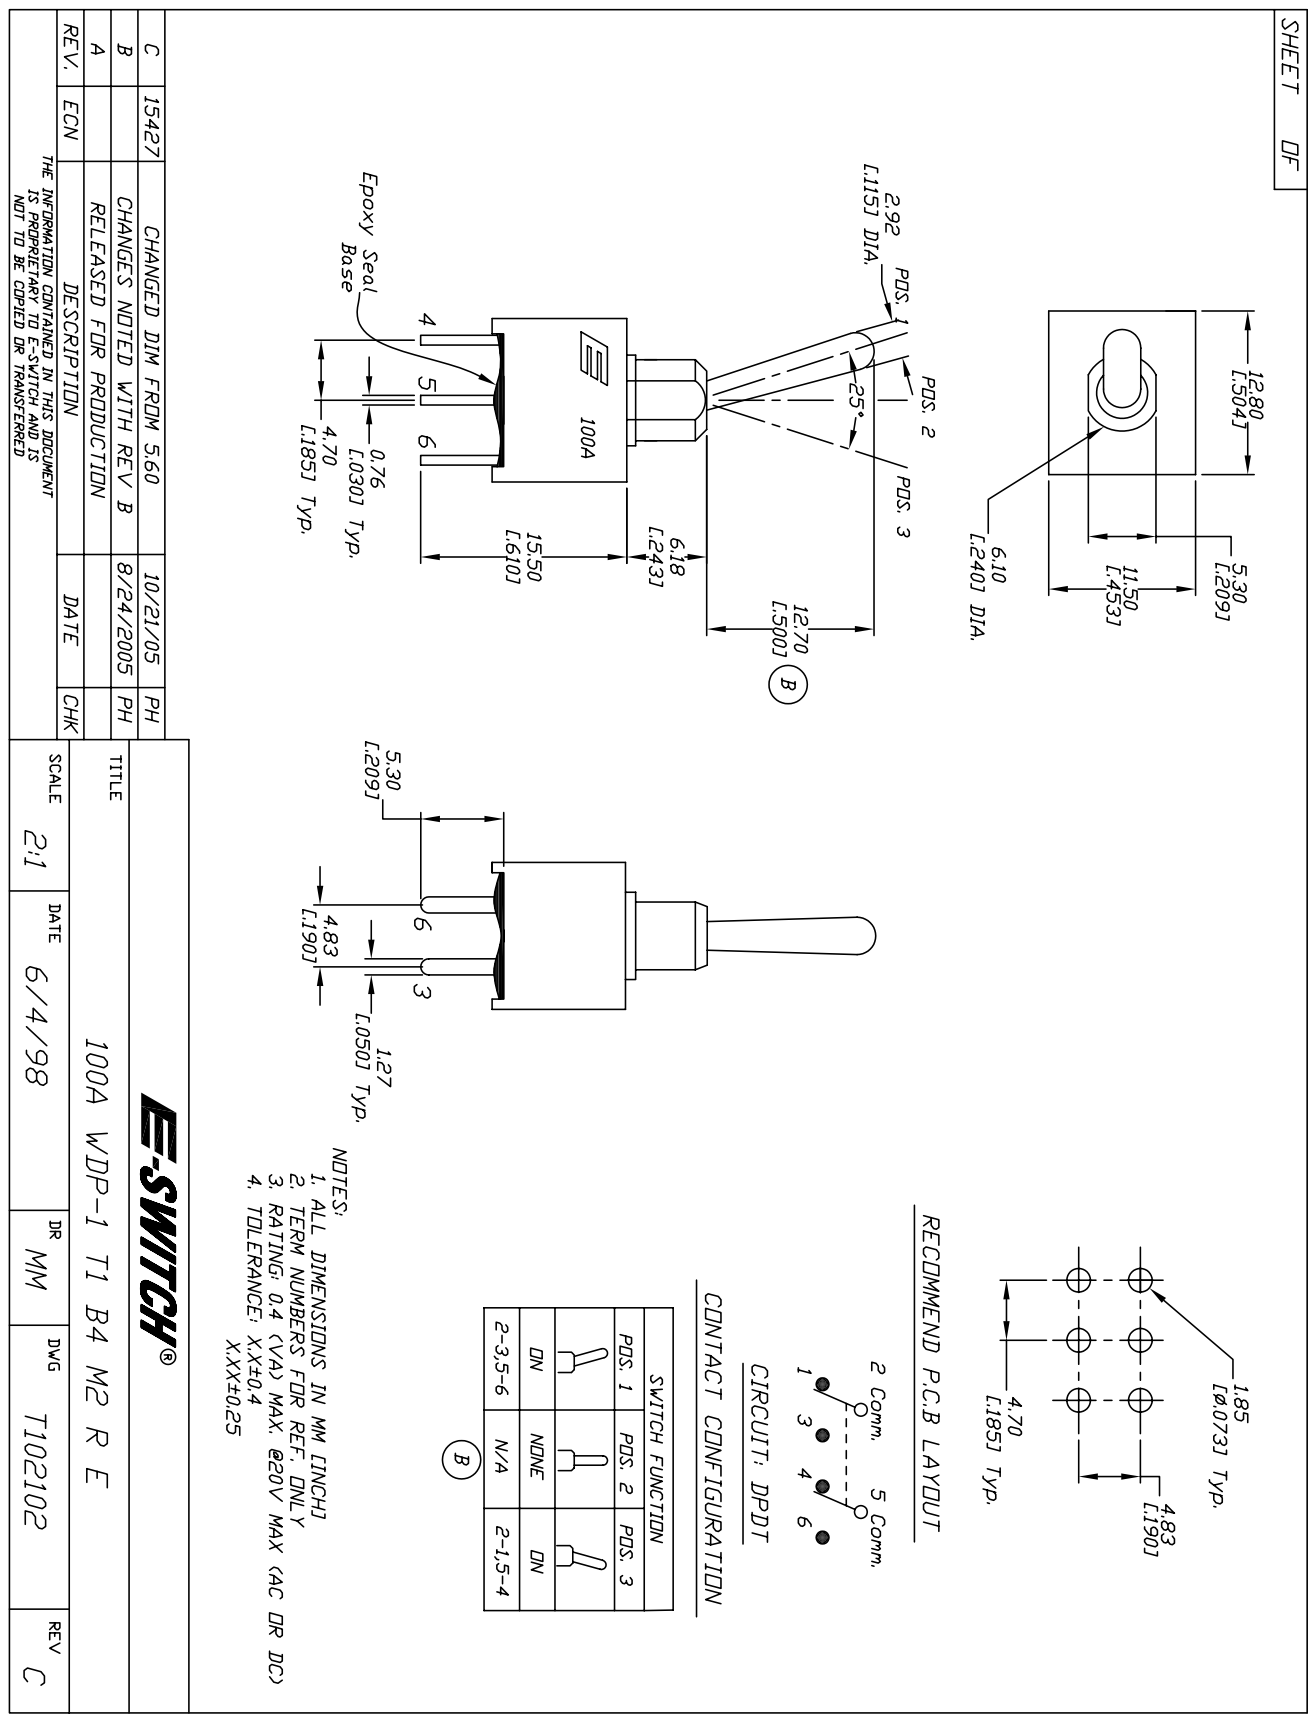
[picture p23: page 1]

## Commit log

2022-05-07 rev 1.1 first upload
    Rev 1.1 with fixes to the PCB, Note that 3D and panel art is not up to date
    [BOM_PartType-HP_Power_Cal.xls, ChopperAmp.SchDoc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]
2025-01-08 Ver 1.1.1 Fixes
    Missing tracks Q3 and C11 installed. Resistor A3A1R1 Value corrected in BOM. Regenerated Gerbers etc ad passes DRM
    [BOM_PartType-HP_Power_Cal.xls, ChopperAmp.SchDoc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]
2025-01-08 Added Calibration Spreadsheet
    Also added data sheets to data folder
    [Calibrate.xlsx, HP_Power_Cal.PrjPcb]
